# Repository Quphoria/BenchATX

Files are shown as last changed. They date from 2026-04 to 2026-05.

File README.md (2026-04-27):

# BenchATX



Bench power supply using an ATX PSU with current sensors  

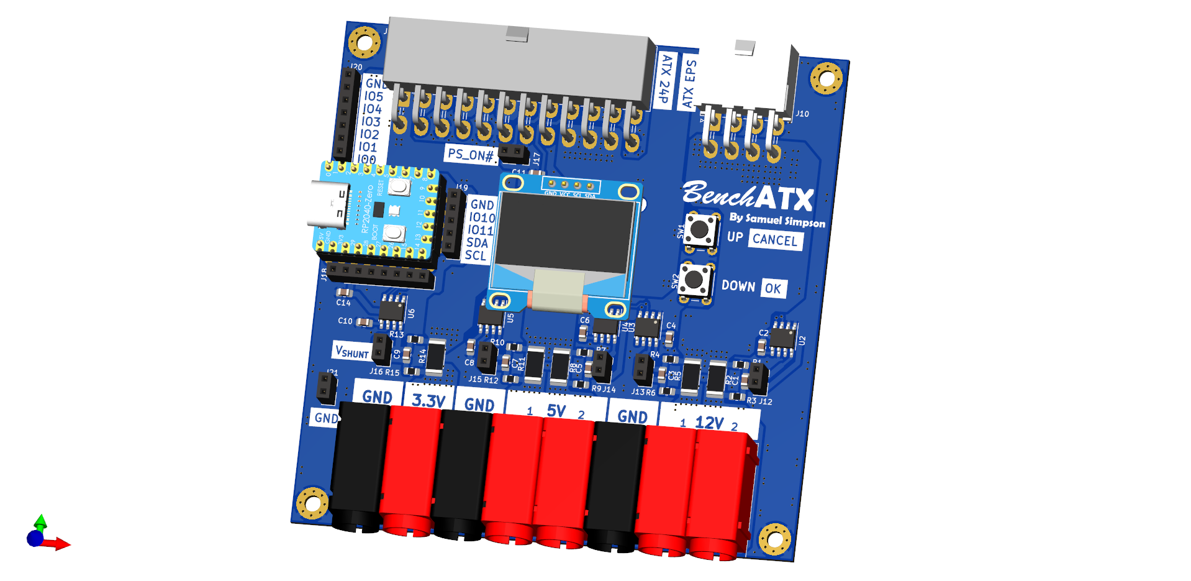
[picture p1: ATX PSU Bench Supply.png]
PCB Render


[Schematic](./ATX%20PSU%20Bench%20Supply%20Schematic.pdf)

## Possible Improvements

- Move OLED up 2.54mm so 1.3" OLEDs won't obstruct the current shunt voltage headers
- Add solder jumpers to swap OLED GND/VCC
- Add solder jumpers to swap OLED between i2c0 and i2c1
- Add a temperature sensor

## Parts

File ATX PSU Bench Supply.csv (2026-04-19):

Source: | C:\Users\TNT_SAMUEL\Documents\KiCad\7.0\projects\ATX PSU Bench Supply\ATX PSU Bench Supply.kicad_sch
Date: | 19/04/2026 01:43:36
Tool: | Eeschema (7.0.0)
Generator: | F:\ProgramFiles\KiCad\7.0\bin\scripting\plugins/bom_csv_grouped_by_value.py
Component Count: | 70
Collated Components:
Item | Qty | Reference(s) | Value | LibPart | Footprint | Datasheet | DNP | ADDR | Mfr. No | Mouser No
1 | 12 | C1, C2, C3, C4, C5, C6, C7, C8, C9, C10, C13, C14 | 0.1uF | Device:C | Capacitor_SMD:C_0805_2012Metric_Pad1.18x1.45mm_HandSolder | ~ |  |  |  | 08055C104JAT2A | 581-08055C104J
2 | 2 | C11, C12 | 1uF | Device:C | Capacitor_SMD:C_0805_2012Metric_Pad1.18x1.45mm_HandSolder | ~ |  |  |  | KGM21AR71C105JU | 581-KGM21AR71C105JU
3 | 4 | H1, H2, H3, H4 | MountingHole_Pad | Mechanical:MountingHole_Pad | MountingHole:MountingHole_3.2mm_M3_Pad_Via | ~
4 | 5 | J1, J2, J4, J5, J7 | 4mm Banana Socket R | Connector:Conn_01x01_Socket | LIB_24.243.1:24.243.1 | ~ |  |  |  | Multicomp 24.243.1
5 | 3 | J3, J6, J8 | 4mm Banana Socket B | Connector:Conn_01x01_Socket | LIB_24.243.1:24.243.2 | ~ |  |  |  | Multicomp 24.243.2
6 | 1 | J9 | Molex 39-30-1240 | Connector:ATX-24 | Connector_Molex:Molex_Mini-Fit_Jr_5569-24A2_2x12_P4.20mm_Horizontal | https://www.intel.com/content/dam/www/public/us/en/documents/guides/power-supply-design-guide-june.pdf |  |  |  | 39-30-1240 | 538-39-30-1240
7 | 1 | J10 | Molex 172448-0008 | Connector_Generic:Conn_02x04_Top_Bottom | Connector_Molex:Molex_Mini-Fit_Jr_5569-08A2_2x04_P4.20mm_Horizontal | ~ |  |  |  | 172448-0008 | 538-172448-0008
8 | 1 | J11 | OLED-128x64 | KLEEB_display:OLED-128x64 | KLEEB_display:OLED-128x64 |  |  |  | ADDR: 0x3C/0x3D
9 | 7 | J12, J13, J14, J15, J16, J17, J21 | Conn_01x02 | Connector_Generic:Conn_01x02 | Connector_PinSocket_2.54mm:PinSocket_1x02_P2.54mm_Vertical | ~
10 | 1 | J18 | Conn_01x08 | Connector_Generic:Conn_01x08 | Connector_PinSocket_2.54mm:PinSocket_1x08_P2.54mm_Vertical | ~
11 | 1 | J19 | Conn_01x05 | Connector_Generic:Conn_01x05 | Connector_PinSocket_2.54mm:PinSocket_1x05_P2.54mm_Vertical | ~
12 | 1 | J20 | Conn_01x07 | Connector_Generic:Conn_01x07 | Connector_PinSocket_2.54mm:PinSocket_1x07_P2.54mm_Vertical | ~
13 | 1 | Q1 | 50C02CH-TL-E | Device:Q_NPN_BEC | Package_TO_SOT_SMD:SOT-23_Handsoldering | ~ |  |  |  | 50C02CH-TL-E | 863-50C02CH-TL-E
14 | 10 | R1, R3, R4, R6, R7, R9, R10, R12, R13, R15 | 10 | Device:R | Resistor_SMD:R_0805_2012Metric_Pad1.20x1.40mm_HandSolder | ~ |  |  |  | CRCW080510R0FKEA | 71-CRCW0805-10-E3
15 | 5 | R2, R5, R8, R11, R14 | 0.005 | Device:R | Resistor_SMD:R_2512_6332Metric_Pad1.40x3.35mm_HandSolder | ~ |  |  |  | MSMA2512R0050FEN | 504-MSMA2512R0050FEN
16 | 2 | R16, R17 | 1.65k | Device:R | Resistor_SMD:R_0805_2012Metric_Pad1.20x1.40mm_HandSolder | ~ | DNP |  |  | CRCW08051K65FKEA | 71-CRCW0805-1.65K-E3
17 | 1 | R18 | 1k | Device:R | Resistor_SMD:R_0805_2012Metric_Pad1.20x1.40mm_HandSolder | ~ |  |  |  | CRCW08051K00FKEA | 71-CRCW0805-1.0K-E3
18 | 1 | R19 | 1.65k | Device:R | Resistor_SMD:R_0805_2012Metric_Pad1.20x1.40mm_HandSolder | ~ |  |  |  | CRCW08051K65FKEA | 71-CRCW0805-1.65K-E3
19 | 1 | R20 | 3.3k | Device:R | Resistor_SMD:R_0805_2012Metric_Pad1.20x1.40mm_HandSolder | ~ |  |  |  | CRCW08053K30FKEA | 71-CRCW0805-3.3K-E3
20 | 1 | R21 | 220 | Device:R | Resistor_SMD:R_0805_2012Metric_Pad1.20x1.40mm_HandSolder | ~ |  |  |  | CRCW0805220RFKEAC | 71-CRCW0805220RFKEAC
21 | 2 | SW1, SW2 | SW_Push | Switch:SW_Push | Button_Switch_THT:SW_PUSH_6mm | ~ |  |  |  | SKHHBWA010 | 688-SKHHBW
22 | 1 | U1 | rp2040-zero | KLEEB_mcu:rp2040-zero | KLEEB_mcu:rp2040-zero-tht
23 | 5 | U2, U3, U4, U5, U6 | INA219BIDR | Sensor_Energy:INA219BxD | Package_SO:SOIC-8_3.9x4.9mm_P1.27mm | http://www.ti.com/lit/ds/symlink/ina219.pdf |  |  |  | INA219BIDR | 595-INA219BIDR
24 | 1 | U7 | TLV75733PDBV | Regulator_Linear:TLV75733PDBV | Package_TO_SOT_SMD:SOT-23-5 | https://www.ti.com/lit/ds/symlink/tlv757p.pdf |  |  |  | TLV75733PDBVR | 595-TLV75733PDBVR

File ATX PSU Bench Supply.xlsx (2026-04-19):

Source: | C:\Users\TNT_SAMUEL\Documents\KiCad\7.0\projects\ATX PSU Bench Supply\ATX PSU Bench Supply.kicad_sch
Date: | 2026-04-19 01:43
Tool: | Eeschema (7.0.0)
Generator: | F:\ProgramFiles\KiCad\7.0\bin\scripting\plugins/bom_csv_grouped_by_value.py
Component Count: | 70
Collated Components:
Item | Qty | Reference(s) | Value | LibPart | Footprint | Datasheet | DNP | ADDR | Mfr. No | Mouser No | Extra | Total | Mouser Bom Copy + Pase
1 | 12 | C1, C2, C3, C4, C5, C6, C7, C8, C9, C10, C13, C14 | 0.1uF | Device:C | Capacitor_SMD:C_0805_2012Metric_Pad1.18x1.45mm_HandSolder | ~ |  |  | 08055C104JAT2A | 581-08055C104J | 18 | 30 | 581-08055C104J|30
2 | 2 | C11, C12 | 1uF | Device:C | Capacitor_SMD:C_0805_2012Metric_Pad1.18x1.45mm_HandSolder | ~ |  |  | KGM21AR71C105JU | 581-KGM21AR71C105JU | 8 | 10 | 581-KGM21AR71C105JU|10
3 | 4 | H1, H2, H3, H4 | MountingHole_Pad | Mechanical:MountingHole_Pad | MountingHole:MountingHole_3.2mm_M3_Pad_Via | ~ |  |  |  |  |  | 4
4 | 5 | J1, J2, J4, J5, J7 | 4mm Banana Socket R | Connector:Conn_01x01_Socket | LIB_24.243.1:24.243.1 | ~ |  |  | Multicomp 24.243.1 |  |  | 5
5 | 3 | J3, J6, J8 | 4mm Banana Socket B | Connector:Conn_01x01_Socket | LIB_24.243.1:24.243.2 | ~ |  |  | Multicomp 24.243.2 |  |  | 3
6 | 1 | J9 | Molex 39-30-1240 | Connector:ATX-24 | Connector_Molex:Molex_Mini-Fit_Jr_5569-24A2_2x12_P4.20mm_Horizontal | https://www.intel.com/content/dam/www/public/us/en/documents/guides/power-supply-design-guide-june.pdf |  |  | 39-30-1240 | 538-39-30-1240 | 1 | 2 | 538-39-30-1240|2
7 | 1 | J10 | Molex 172448-0008 | Connector_Generic:Conn_02x04_Top_Bottom | Connector_Molex:Molex_Mini-Fit_Jr_5569-08A2_2x04_P4.20mm_Horizontal | ~ |  |  | 172448-0008 | 538-172448-0008 | 1 | 2 | 538-172448-0008|2
8 | 1 | J11 | OLED-128x64 | KLEEB_display:OLED-128x64 | KLEEB_display:OLED-128x64 |  |  | ADDR: 0x3C/0x3D |  |  |  | 1
9 | 7 | J12, J13, J14, J15, J16, J17, J21 | Conn_01x02 | Connector_Generic:Conn_01x02 | Connector_PinSocket_2.54mm:PinSocket_1x02_P2.54mm_Vertical | ~ |  |  |  |  |  | 7
10 | 1 | J18 | Conn_01x08 | Connector_Generic:Conn_01x08 | Connector_PinSocket_2.54mm:PinSocket_1x08_P2.54mm_Vertical | ~ |  |  |  |  |  | 1
11 | 1 | J19 | Conn_01x05 | Connector_Generic:Conn_01x05 | Connector_PinSocket_2.54mm:PinSocket_1x05_P2.54mm_Vertical | ~ |  |  |  |  |  | 1
12 | 1 | J20 | Conn_01x07 | Connector_Generic:Conn_01x07 | Connector_PinSocket_2.54mm:PinSocket_1x07_P2.54mm_Vertical | ~ |  |  |  |  |  | 1
13 | 1 | Q1 | 50C02CH-TL-E | Device:Q_NPN_BEC | Package_TO_SOT_SMD:SOT-23_Handsoldering | ~ |  |  | 50C02CH-TL-E | 863-50C02CH-TL-E | 4 | 5 | 863-50C02CH-TL-E|5
14 | 10 | R1, R3, R4, R6, R7, R9, R10, R12, R13, R15 | 10 | Device:R | Resistor_SMD:R_0805_2012Metric_Pad1.20x1.40mm_HandSolder | ~ |  |  | CRCW080510R0FKEA | 71-CRCW0805-10-E3 | 10 | 20 | 71-CRCW0805-10-E3|20
15 | 5 | R2, R5, R8, R11, R14 | 0.005 | Device:R | Resistor_SMD:R_2512_6332Metric_Pad1.40x3.35mm_HandSolder | ~ |  |  | MSMA2512R0050FEN | 504-MSMA2512R0050FEN | 10 | 15 | 504-MSMA2512R0050FEN|15
16 | 2 | R16, R17 | 1.65k | Device:R | Resistor_SMD:R_0805_2012Metric_Pad1.20x1.40mm_HandSolder | ~ | DNP |  | CRCW08051K65FKEA | 71-CRCW0805-1.65K-E3 | 8 | 10 | 71-CRCW0805-1.65K-E3|10
17 | 1 | R18 | 1k | Device:R | Resistor_SMD:R_0805_2012Metric_Pad1.20x1.40mm_HandSolder | ~ |  |  | CRCW08051K00FKEA | 71-CRCW0805-1.0K-E3 | 10 | 11 | 71-CRCW0805-1.0K-E3|11
18 | 1 | R19 | 1.65k | Device:R | Resistor_SMD:R_0805_2012Metric_Pad1.20x1.40mm_HandSolder | ~ |  |  | CRCW08051K65FKEA | 71-CRCW0805-1.65K-E3 | 10 | 11 | 71-CRCW0805-1.65K-E3|11
19 | 1 | R20 | 3.3k | Device:R | Resistor_SMD:R_0805_2012Metric_Pad1.20x1.40mm_HandSolder | ~ |  |  | CRCW08053K30FKEA | 71-CRCW0805-3.3K-E3 | 10 | 11 | 71-CRCW0805-3.3K-E3|11
20 | 1 | R21 | 220 | Device:R | Resistor_SMD:R_0805_2012Metric_Pad1.20x1.40mm_HandSolder | ~ |  |  | CRCW0805220RFKEAC | 71-CRCW0805220RFKEAC | 10 | 11 | 71-CRCW0805220RFKEAC|11
21 | 2 | SW1, SW2 | SW_Push | Switch:SW_Push | Button_Switch_THT:SW_PUSH_6mm | ~ |  |  | SKHHBWA010 | 688-SKHHBW | 8 | 10 | 688-SKHHBW|10
22 | 1 | U1 | rp2040-zero | KLEEB_mcu:rp2040-zero | KLEEB_mcu:rp2040-zero-tht |  |  |  |  |  |  | 1
23 | 5 | U2, U3, U4, U5, U6 | INA219BIDR | Sensor_Energy:INA219BxD | Package_SO:SOIC-8_3.9x4.9mm_P1.27mm | http://www.ti.com/lit/ds/symlink/ina219.pdf |  |  | INA219BIDR | 595-INA219BIDR | 5 | 10 | 595-INA219BIDR|10
24 | 1 | U7 | TLV75733PDBV | Regulator_Linear:TLV75733PDBV | Package_TO_SOT_SMD:SOT-23-5 | https://www.ti.com/lit/ds/symlink/tlv757p.pdf |  |  | TLV75733PDBVR | 595-TLV75733PDBVR | 4 | 5 | 595-TLV75733PDBVR|5

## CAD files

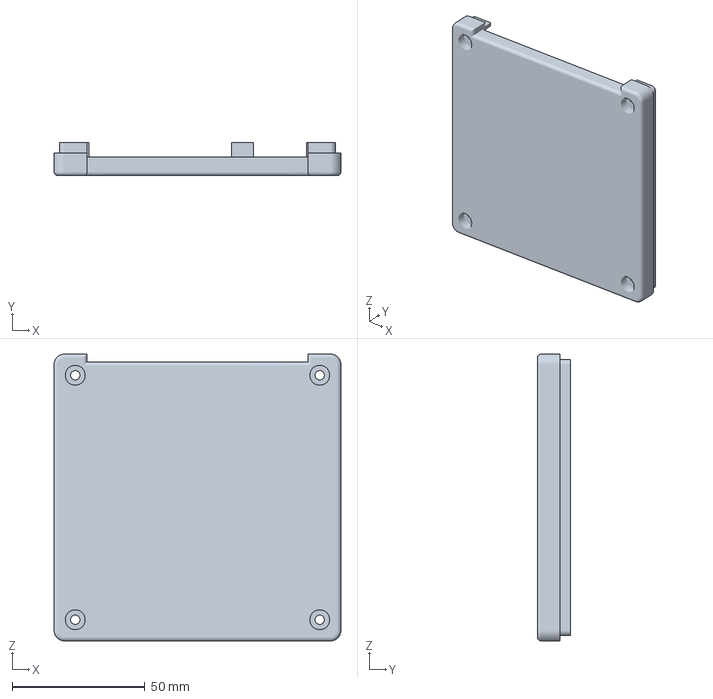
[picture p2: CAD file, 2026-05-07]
case/BenchATX Case Bottom.3mf
108.0 x 12.6 x 108.0 mm

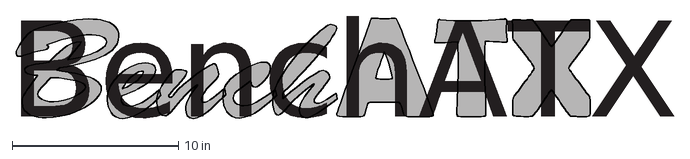
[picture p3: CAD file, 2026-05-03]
graphics/BenchATX Logo.dxf
BenchATX

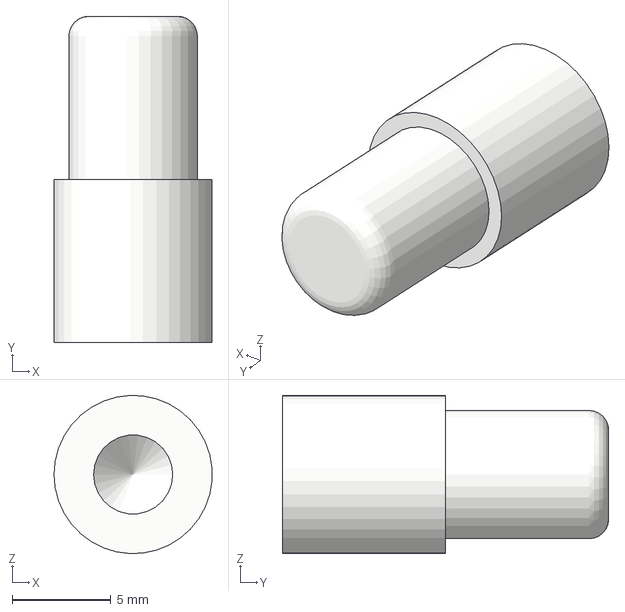
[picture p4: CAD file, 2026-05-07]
case/BenchATX Case Button.3mf
7.99 x 16.5 x 7.99 mm

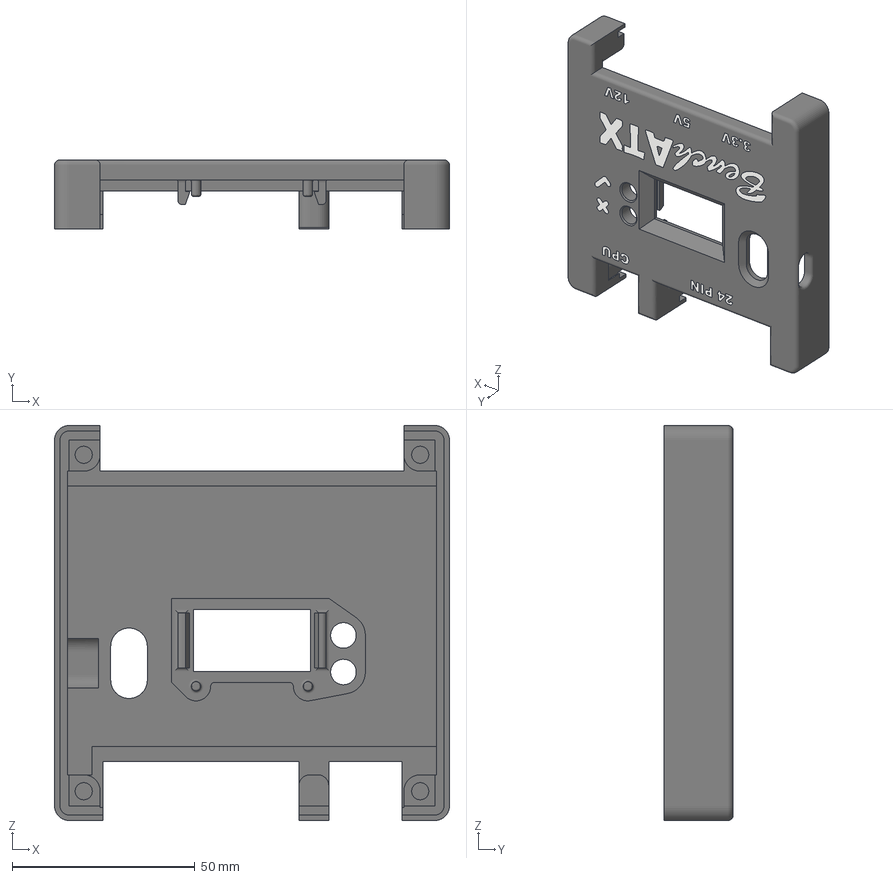
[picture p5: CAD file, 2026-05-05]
case/BenchATX Case Top 1.3 OLED.3mf
108.0 x 19.0 x 108.0 mm
BenchATX Top Case

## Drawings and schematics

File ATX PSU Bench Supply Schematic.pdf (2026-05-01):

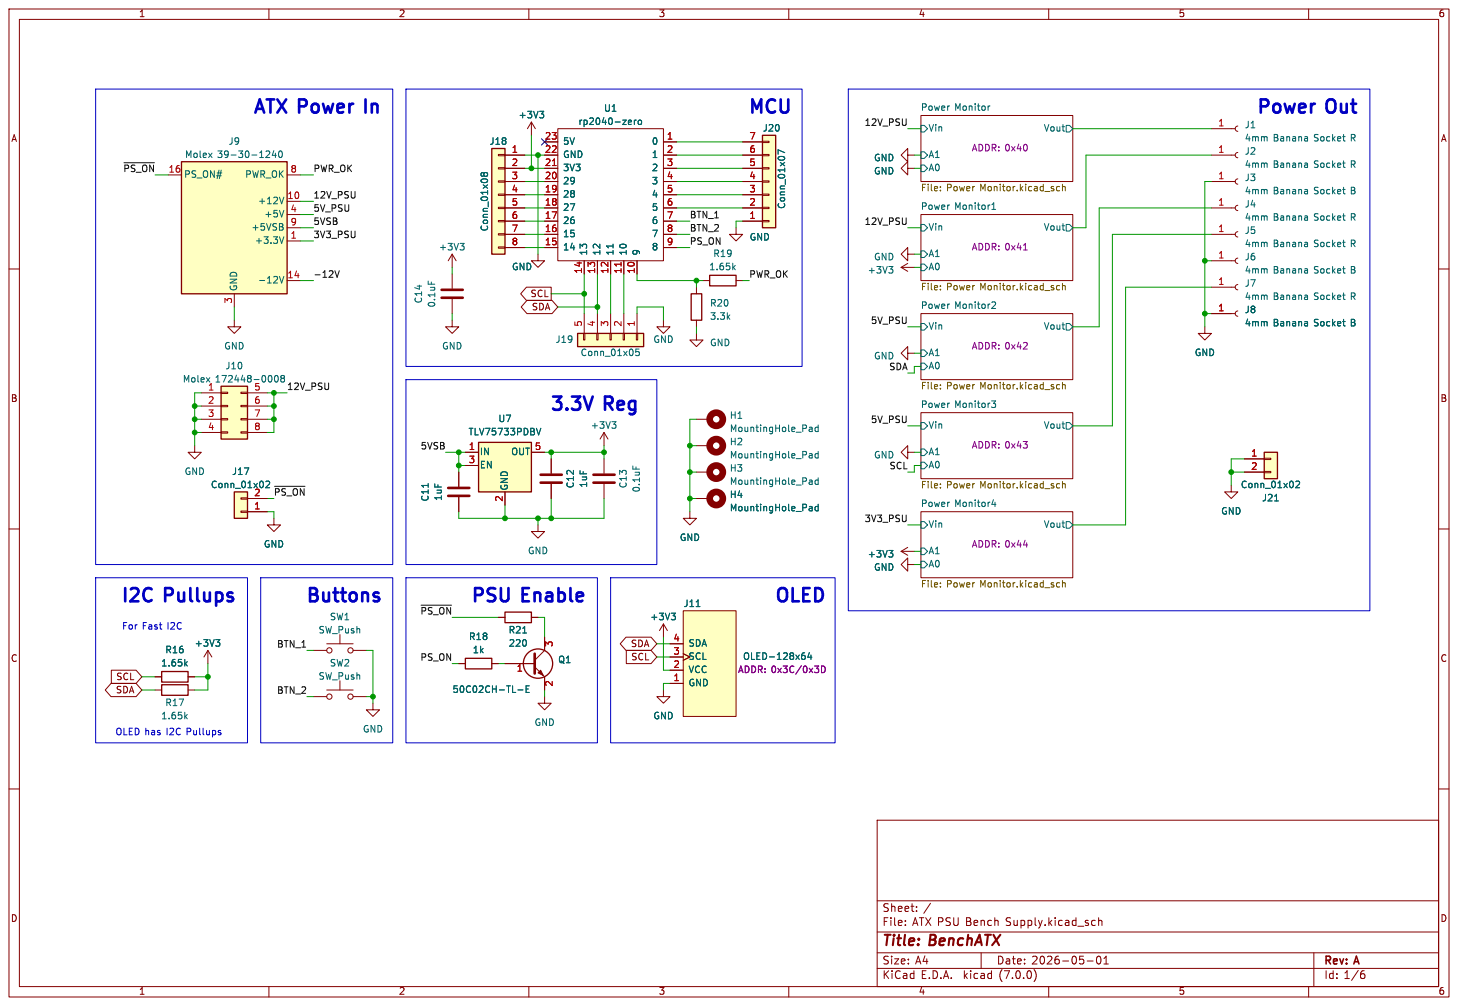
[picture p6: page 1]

Power Out OLED has I2C Pullups

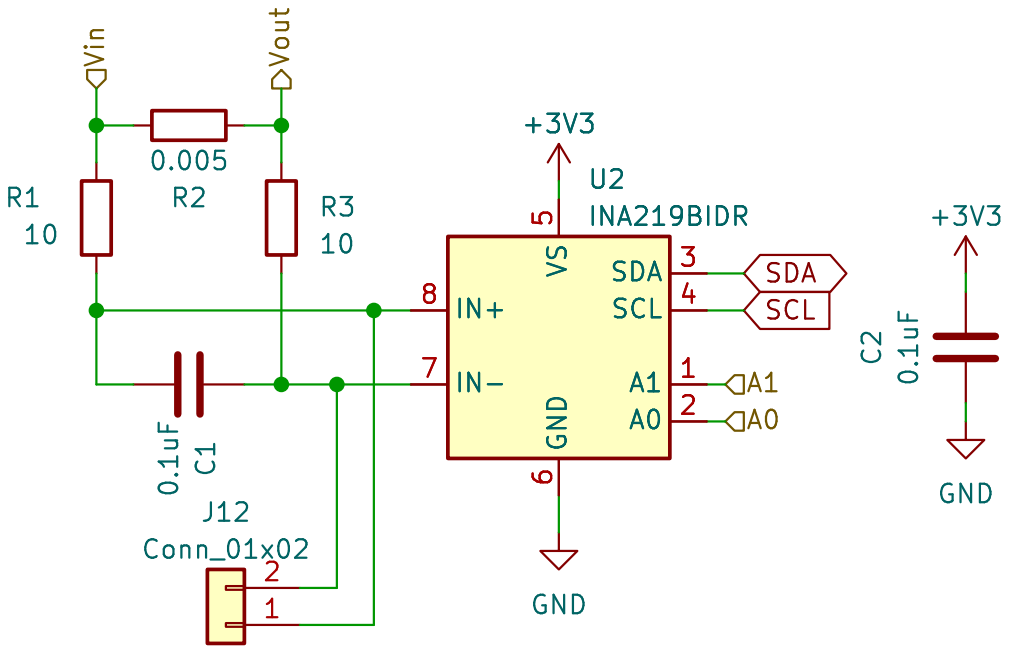
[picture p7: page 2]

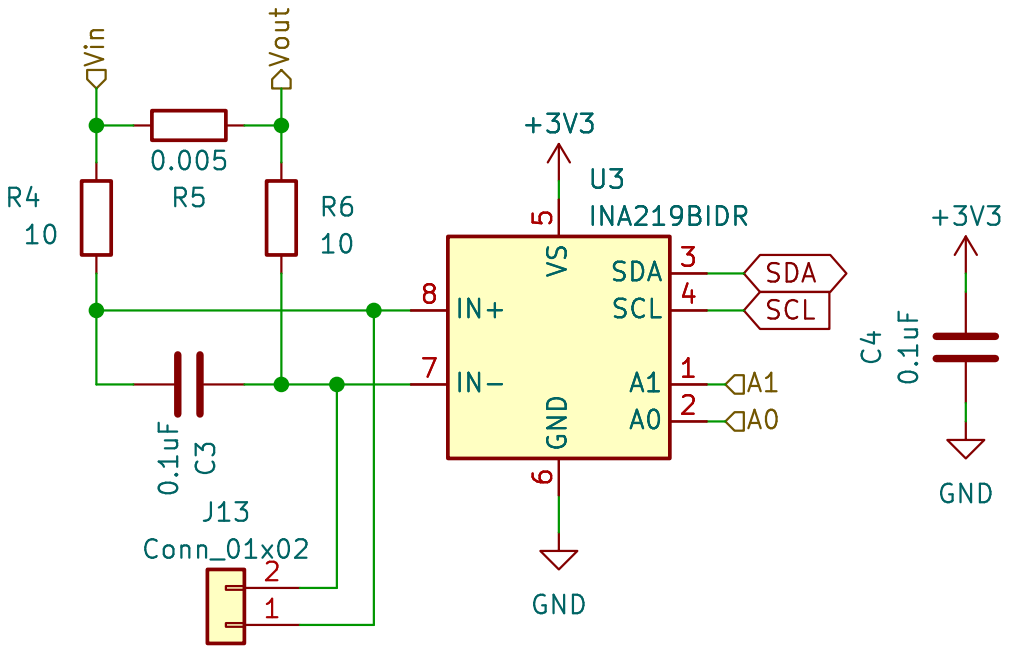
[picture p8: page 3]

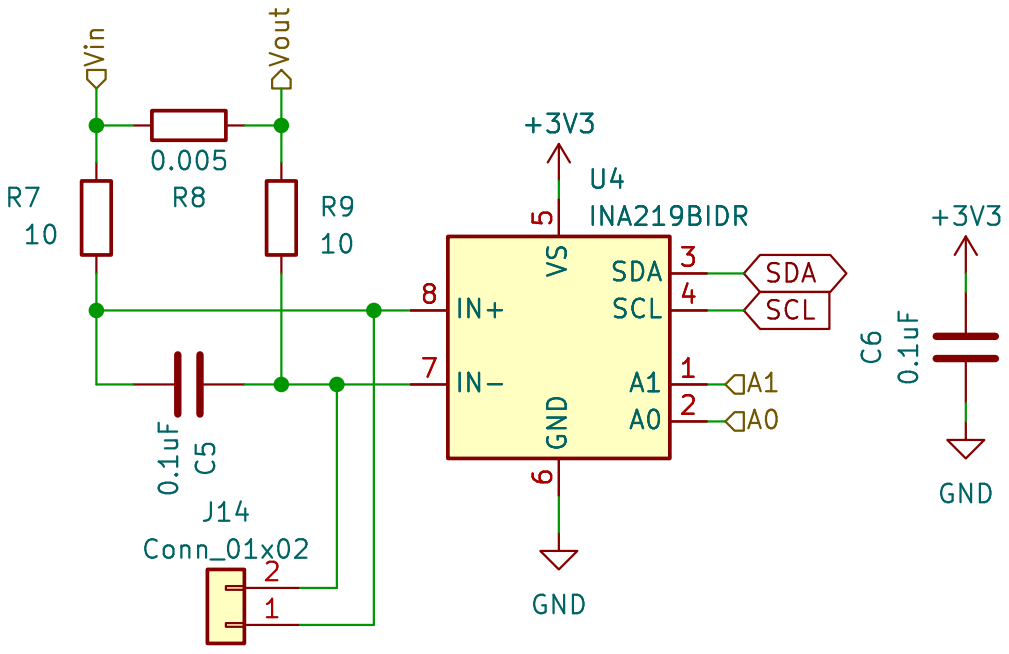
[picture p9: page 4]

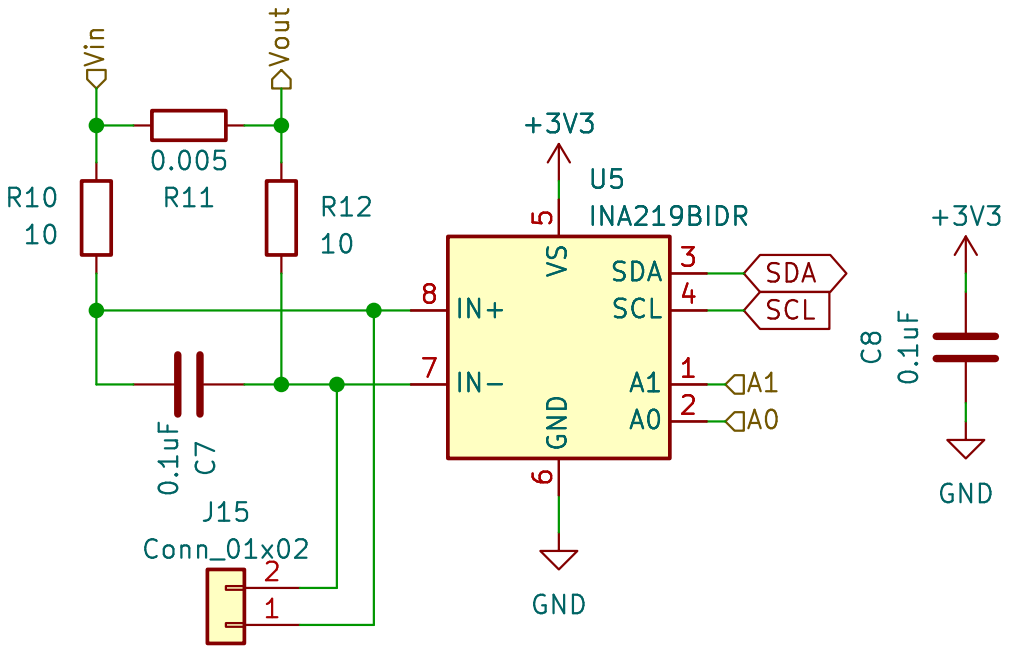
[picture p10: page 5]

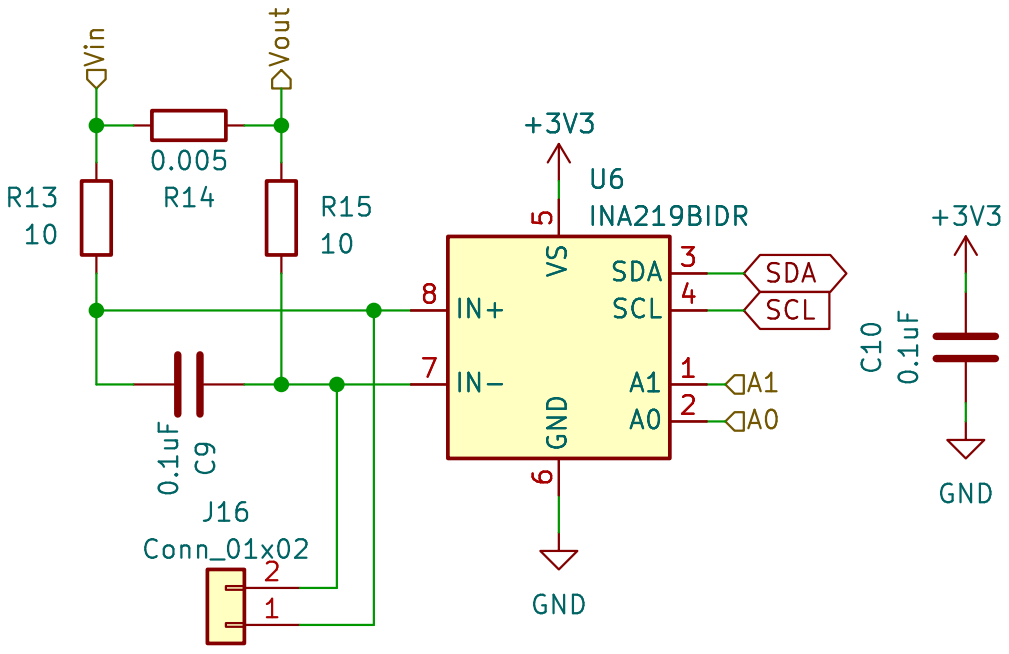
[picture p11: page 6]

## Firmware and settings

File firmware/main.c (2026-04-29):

#include <stdio.h>

#include "pico/stdlib.h"
#include "pico/unique_id.h"
// To allow reset to bootloader
#include "pico/bootrom.h"
#include "pico/time.h"
#include "hardware/i2c.h"
#include "hardware/watchdog.h"

#include "buttons.h"
#include "display.h"
#include "power_sensor.h"
#include "status_led.h"
#include "settings.h"

#define WATCHDOG_TIMEOUT_MS 2000
#define WATCHDOG_UPDATE_TIMER_MS 500

#define BOARD_ID_STR_LEN (2 * PICO_UNIQUE_BOARD_ID_SIZE_BYTES + 1)

static bool initialized = false;
static bool alive = true;

static void process_command(const char *cmd);

bool watchdog_update_timer_callback(struct repeating_timer *t) {
    if (!initialized) return true;
    if (!alive) return true;
    alive = false;

    watchdog_update();

    return true;
}

static struct repeating_timer watchdog_update_timer;

void setup_i2c(void) {
    i2c_init(i2c0, 400 * 1000); // 400kHz I2C Fast Mode
    gpio_set_function(12, GPIO_FUNC_I2C);
    gpio_set_function(13, GPIO_FUNC_I2C);
    gpio_pull_up(12);
    gpio_pull_up(13);
}

static void enter_bootloader(void) {
    // Enter the bootloader
    reset_usb_boot(0,0); // No activity led
}

static const uint LED_PIN = 25;
static const uint PS_ON_PIN = 8;
static const uint PWR_OK_PIN = 9;

static inline void init_btns() {
    for (uint8_t i = 0; i < NUM_BTNS; i++) {
        gpio_init(btn_status.pins[i]);
        gpio_set_dir(btn_status.pins[i], GPIO_IN);
        gpio_set_pulls(btn_status.pins[i], true, false); // Enable pullup
        btn_status.prev_state[i] = true;
        btn_status.debounce_delay[i] = get_absolute_time();
    }
}

static inline uint8_t check_btn(uint8_t index) {
    if (index >= 2) return 0;

    absolute_time_t t = get_absolute_time();

    // Check if delay expiry is in the future
    if (absolute_time_diff_us(t, btn_status.debounce_delay[index]) >= 0) return 0;

    // Reuse debounce delay timeout time, just subtract the debounce delay
    bool long_press = !btn_status.prev_state[index] && absolute_time_diff_us(btn_status.debounce_delay[index], t) > 1000*(LONG_PRESS_MS-DEBOUNCE_DELAY_MS);
    if (long_press && !btn_status.long_press[index]) {
        btn_status.long_press[index] = true;
        return LONG_PRESS;
    }

    bool new_state = gpio_get(btn_status.pins[index]);
    if (btn_status.prev_state[index] != new_state) {
        btn_status.prev_state[index] = new_state;
        btn_status.debounce_delay[index] = make_timeout_time_ms(DEBOUNCE_DELAY_MS); // 50ms debounce
        btn_status.long_press[index] = false;
        if (new_state == 1 && !long_press) { // 0 -> 1
            return SHORT_PRESS;
        }
    }
    return 0;
}

int main() {
    sleep_ms(500); // Wait for usb to disconnect before connecting
    stdio_init_all();

    gpio_init(PS_ON_PIN);
    gpio_set_dir(PS_ON_PIN, GPIO_OUT);
    gpio_put(PS_ON_PIN, false);

    gpio_init(PWR_OK_PIN);
    gpio_set_dir(PWR_OK_PIN, GPIO_IN);

    printf("\n\n\n\n\n");
    printf("BenchATX\n");

    if (watchdog_caused_reboot() &&
        watchdog_enable_caused_reboot()) printf("Rebooted by Watchdog!\n");

    pico_unique_board_id_t board_id;
    char board_id_str[BOARD_ID_STR_LEN] = "";
    pico_get_unique_board_id(&board_id);
    pico_get_unique_board_id_string(board_id_str, BOARD_ID_STR_LEN);
    printf("Board ID: %s\n", board_id_str);

    add_repeating_timer_ms(WATCHDOG_UPDATE_TIMER_MS, watchdog_update_timer_callback, NULL, &watchdog_update_timer);

    // Start watchdog
    watchdog_enable(WATCHDOG_TIMEOUT_MS, true); // Pause watchdog on debug
    
    load_settings();
    
    printf("Initializing peripherals...\n");
    setup_i2c();
    init_btns();
    init_status_led(pio0);
    init_power_sensors();
    init_display();

#ifndef SH1106
    if (settings.disp_contrast == 0) {
        show_popup_centered(63, 31, 2, 2000, 7, 2, "Display\n  Off");
    }
#endif

    uint8_t current_screen = 0;
    bool is_on = false;
    absolute_time_t measure_delay = get_absolute_time();

    if (settings.startup_state) {
        is_on = true;
        printf("(Startup) Turning PSU ON\n");
        update_on_state(is_on);
        gpio_put(PS_ON_PIN, is_on);
    }

    set_status_led(0x00, 0x60, 0x04, false);
    initialized = true;

    bool settings_open = false;
    char cmd_buf[64];
    uint8_t cmd_len = 0;

    gpio_init(LED_PIN);
    gpio_set_dir(LED_PIN, GPIO_OUT);
    int led = 0;
    while (true) {
        alive = true;

        led = ~led;
        gpio_put(LED_PIN, led);

        while (true) {
            int ch = getchar_timeout_us(0);
            if (ch == PICO_ERROR_TIMEOUT) break;

            char c = ch;
            putchar(c); // Echo character
            if (cmd_len >= sizeof(cmd_buf)) {
                printf("Error: Command buffer overflow\n");
                cmd_len = 0;
            } else if (c == '\n' || c == '\r') {
                printf("\n");
                // Process command (will print help prompt if empty)
                cmd_buf[cmd_len] = 0;
                cmd_len = 0;
                process_command(cmd_buf);
            } else if (c == '\b') {
                // Backspace
                if (cmd_len > 0) cmd_len--;
                printf(" \b"); // Clear previous character in terminal
            } else {
                // Append to buffer
                cmd_buf[cmd_len++] = c;
            }
        }

        if (absolute_time_diff_us(get_absolute_time(), measure_delay) < 0) {
            measure_delay = make_timeout_time_ms(100); // Measure every 100ms

            if (settings.uart_logging) {
                printf("\n");
            }

            for (uint8_t i = 0; i < NUM_POWER_SENSORS; i++) {
                // Address order is backwards
                float v = power_sens_get_voltage(NUM_POWER_SENSORS-1-i);
                float c = power_sens_get_current(NUM_POWER_SENSORS-1-i);
                bool ovf = power_sens_get_overflow(NUM_POWER_SENSORS-1-i);

                switch (settings.uart_logging) {
                    case LOGGING_PLAIN:
                        printf("[CH %0d] Voltage: %6.3f V, Current %.1f mA%s\n", i, v, c*1000, ovf ? " OVERFLOW!!!" : "");
                        break;
                    case LOGGING_CSV:
                        printf("%0d,%.3f,%.1f,%0d\n", i, v, c*1000, ovf ? 1 : 0);
                        break;
                }
                
                update_voltage(i, v*1000);
                update_current(i, c*10000);
                update_overflow(i, ovf);
            }
        }

        uint8_t btn1 = check_btn(0);
        uint8_t btn2 = check_btn(1);
        bool change_screen = false;

        if (settings_open) {
            // Settings menu takes control of buttons when open
            if (update_settings_menu(btn1, btn2)) {
                settings_open = false;
                current_screen = 0;
                change_screen = true;
            }
        } else {
            if (btn1 == SHORT_PRESS && btn2 == SHORT_PRESS) {
                // Do nothing
            } else if (btn1 == SHORT_PRESS ) {
                if (current_screen == 0) current_screen = NUM_SCREENS-1;
                else current_screen -= 1;
                change_screen = true;
            } else if (btn2 == SHORT_PRESS) {
                current_screen = (current_screen + 1) % NUM_SCREENS;
                change_screen = true;
            } else if (btn1 == LONG_PRESS) {
                // Shortcut to settings if on screen 0
                if (current_screen == 0) {
                    set_current_screen(SETTINGS_SCREEN);
                    open_settings();
                    settings_open = true;
                } else {
                    current_screen = 0;
                    change_screen = true;
                }
            } else if (btn2 == LONG_PRESS) {
                if (current_screen == SETTINGS_SCREEN) {
                    open_settings();
                    settings_open = true;
                } else {
                    // Toggle power on other screens
                    is_on = !is_on;
                    printf("Turning PSU %s\n", is_on ? "ON" : "OFF");
                    update_on_state(is_on);
                    gpio_put(PS_ON_PIN, is_on);
                }
            }
        }

        if (change_screen) set_current_screen(current_screen);

        update_pwr_ok(gpio_get(PWR_OK_PIN));

        refresh_display();
    }
}

static void process_command(const char *cmd) {
    if (strcmp(cmd, "update") == 0) {
        printf("Entering Bootloader...\n");
        show_popup_centered(63, 31, 2, 1000, 6, 2, "Update\n Mode");
        refresh_display();
        sleep_ms(100);
        enter_bootloader();
    } else if (strcmp(cmd, "help") == 0) {
        printf("Available comamands:\n"
               "  update    - Enters the bootloader for updating firmware\n"
               "  help      - Prints this help message\n"
        );
    } else {
        if (strlen(cmd) != 0) {
            printf("Unknown command: %s\n", cmd);
        }
        printf("Type 'help' to view a list of valid commands\n");
    }
}

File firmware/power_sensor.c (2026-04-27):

#include <stdio.h>
#include <math.h>
#include "pico/stdlib.h"
#include "hardware/i2c.h"

#include "power_sensor.h"

#define POWER_SENS_I2C i2c0
#define POWER_SENS_START_ADDR 0x40

#define PWR_REG_CONFIG  0
#define PWR_REG_SHUNT_V 1
#define PWR_REG_BUS_V   2
#define PWR_REG_POWER   3
#define PWR_REG_CURRENT 4
#define PWR_REG_CALIBR  5

#define PWR_CFG_RESET   (1<<15)
#define PWR_CFG_BRNG    (0<<13) // Bus Voltage Range: 16V FSR
#define PWR_CFG_PG      (0b01<<11) // +-80mV Shunt Voltage
#define PWR_CFG_BADC    (0b1011<<7) // Bus ADC Res/Avg 8 samples = 4.26ms conversion time 
#define PWR_CFG_SADC    (0b1011<<3) // Shunt ADC Res/Avg 8 samples = 4.26ms conversion time 
#define PWR_CFG_MODE    (0b111) // Mode: Shunt and bus, continuous

// Cal = 0.04096 / (Current_LSB * Rshunt)
// Current_LSB = (Max Expected Current / 2^15)
// RShunt = 0.005
// Max Expected current = 20A
// Cal = 13421
// Shunt Voltage Register Max = 8000
// Giving us (8000 * 16777) / 4096 = 32767
// 32767 * Current_LSB = 19.999A

#define MAX_EXPECTED_CURRENT 20
#define CURRENT_LSB (MAX_EXPECTED_CURRENT / pow(2, 15))
#define POWER_LSB (20*CURRENT_LSB)
#define PWR_CALIBRATION_VALUE 16777

void power_sens_write_reg(uint8_t sensor, uint8_t reg, uint16_t val);
uint16_t power_sens_read_reg(uint8_t sensor, uint8_t reg);

void init_power_sensors(void) {
#ifdef DUMMY_SENSOR
    return;
#endif
    for (uint8_t i = 0; i < NUM_POWER_SENSORS; i++) {
        // First reset chip
        power_sens_write_reg(i, PWR_REG_CONFIG, PWR_CFG_RESET);
        // Now set config
        power_sens_write_reg(i, PWR_REG_CONFIG,
            PWR_CFG_BRNG | PWR_CFG_PG | PWR_CFG_BADC | PWR_CFG_SADC | PWR_CFG_MODE
        ); // Set MODE
    
        // Write calibration value
        power_sens_write_reg(i, PWR_REG_CALIBR, PWR_CALIBRATION_VALUE);
    }

    sleep_ms(5); // Wait for 5ms for first measurements to be made
}

static bool in_overflow[NUM_POWER_SENSORS] = {0};

bool power_sens_get_overflow(uint8_t sensor) {
    if (sensor >= NUM_POWER_SENSORS) panic("Invalid power sensor ID");
    return in_overflow[sensor];
}

float power_sens_get_voltage(uint8_t sensor) {
#ifdef DUMMY_SENSOR
    return 1.234;
#endif
    int16_t value = power_sens_read_reg(sensor, PWR_REG_BUS_V);
    if (value & 0b1) printf("Warning: Power Sensor Overflow (Current/Power may be invalid)\n");
    in_overflow[sensor] = value & 0b1;
    // Don't check conversion bit as we are in continuous mode
    float voltage = (float)(value >> 3);
    voltage *= 0.004;
    return voltage;
}

float power_sens_get_current(uint8_t sensor) {
#ifdef DUMMY_SENSOR
    return 12.3456;
#endif
    float current = (int16_t)power_sens_read_reg(sensor, PWR_REG_CURRENT);
    current *= CURRENT_LSB;
    return current;
}

float power_sens_get_power(uint8_t sensor) {
#ifdef DUMMY_SENSOR
    return 123.456;
#endif
    float power = (int16_t)power_sens_read_reg(sensor, PWR_REG_POWER);
    power *= POWER_LSB;
    return power;
}

void power_sens_write_reg(uint8_t sensor, uint8_t reg, uint16_t val) {
    if (sensor >= NUM_POWER_SENSORS) panic("Invalid power sensor ID");
    uint8_t data[3] = {reg, (val >> 8) & 0xff, val & 0xff};

    int ret = i2c_write_blocking(POWER_SENS_I2C, POWER_SENS_START_ADDR + sensor, data, 3, false);
    if (ret == PICO_ERROR_GENERIC) panic("Failed to write to power sensor");
}

uint16_t power_sens_read_reg(uint8_t sensor, uint8_t reg) {
    if (sensor >= NUM_POWER_SENSORS) panic("Invalid power sensor ID");

    int ret = i2c_write_blocking(POWER_SENS_I2C, POWER_SENS_START_ADDR + sensor, &reg, 1, true);
    if (ret == PICO_ERROR_GENERIC) panic("Failed to write to power sensor");

    uint8_t data[2];

    ret = i2c_read_blocking(POWER_SENS_I2C, POWER_SENS_START_ADDR + sensor, data, 2, false);
    if (ret == PICO_ERROR_GENERIC) panic("Failed to read from power sensor");

    uint16_t value = (data[0] << 8) | data[1];
    return value;
}

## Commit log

2026-04-18 Add schematic
2026-04-18 Fix schematic I2C address, add firmware dir
    [ATX PSU Bench Supply.kicad_sch]
2026-04-18 Add DNP to I2C Pullups
    [ATX PSU Bench Supply.kicad_sch]
2026-04-19 Fix some component model numbers
    [ATX PSU Bench Supply.csv, ATX PSU Bench Supply.kicad_sch, ATX PSU Bench Supply.xlsx]
2026-04-27 Move pico-sdk to tmp
2026-04-27 Try caching pico-sdk
2026-04-27 Add command handler, fix usb not connecting on boot
    [display.c, main.c]
2026-04-29 Add constrast, logging mode settings, improve uart console
2026-05-01 Add interactive BOM
2026-05-01 Set PCB Revision
2026-05-01 Set PCB metadata
    [ATX PSU Bench Supply.kicad_sch, Power Monitor.kicad_sch]
2026-05-02 Fix bug, use real power sensors
    [display.c]
2026-05-03 Add logo DXF, use SH1106
    [BenchATX Logo.dxf]
2026-05-05 Add 3D printable case files
    [BenchATX Case Bottom.3mf, BenchATX Case Button.3mf, BenchATX Case Top 1.3 OLED.3mf]
2026-05-05 Update 3D Printable case
    [BenchATX Case Button.3mf, BenchATX Case Top 1.3 OLED.3mf]
2026-05-05 Update 3D printable case bottom
    [BenchATX Case Bottom.3mf]
2026-05-05 Update 3D printable case top
    [BenchATX Case Top 1.3 OLED.3mf]
2026-05-07 Update case buttom and buttons
    [BenchATX Case Bottom.3mf, BenchATX Case Button.3mf]
